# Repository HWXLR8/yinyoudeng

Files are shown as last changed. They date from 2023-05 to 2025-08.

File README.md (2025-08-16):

# 音游灯

<p float="left">
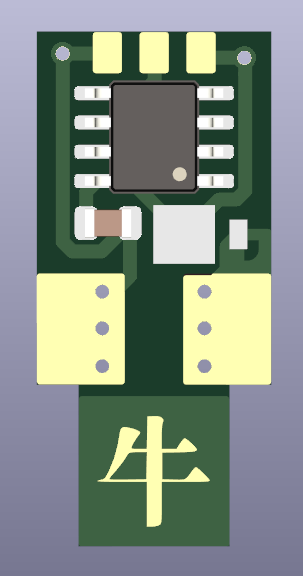
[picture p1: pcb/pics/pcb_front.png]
  
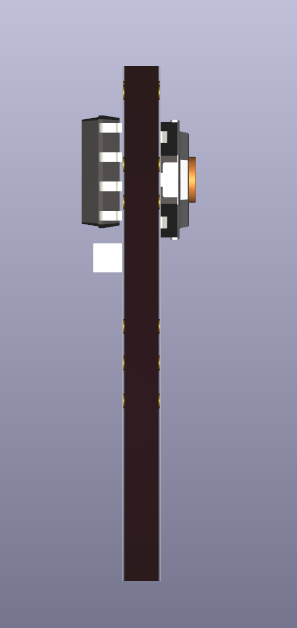
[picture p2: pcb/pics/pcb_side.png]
  
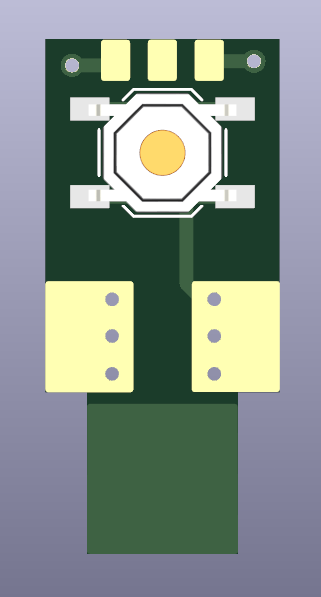
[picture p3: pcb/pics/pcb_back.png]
  
</p>
This is an RGB LED for use with Sanwa rhythm game buttons (also compaitible with many chinese clone buttons). Intended to be soldered to those cheap WS2812 circular PCBs readily available on Aliexpress which include on-board current limiting resistors and decoupling caps:

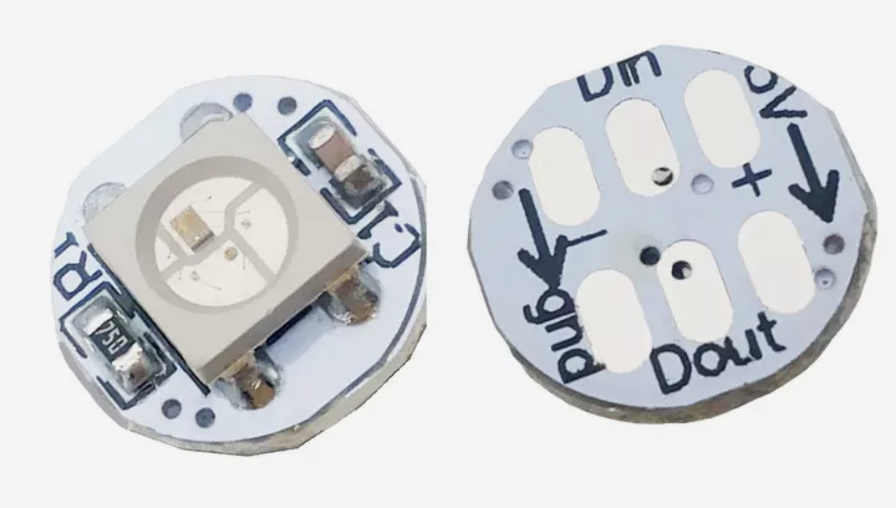
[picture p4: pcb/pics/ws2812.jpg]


BOM:
```
1 ATTINY13A-SSU
1 100nF SMD cap 0805
1 schottky diode (MFG# UPS115UE3)
1 4x4x1.5mm tactile SMD tactile push button
1 WS2812 LED on PCB with res+cap
```
PCBs should be manufactured at 2.0mm thickness instead of standard 1.6mm. Soldering the WS2812 module on to the PCB can be a bit tricky, so I designed a jig which simplifies the alignment of the parts. The model is available in `jig/jig.stl`.

Special thanks to Tim (cpldcpu) for the <a href="https://github.com/cpldcpu/light_ws2812">implementation of
the WS2812 protocol</a>.

享受音游 享受生活

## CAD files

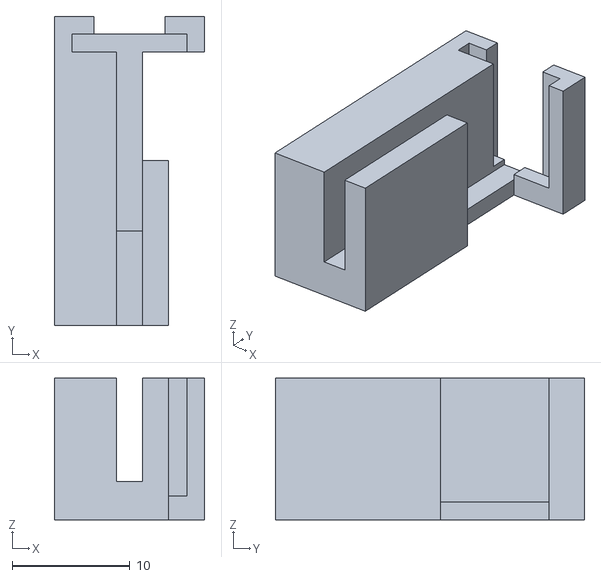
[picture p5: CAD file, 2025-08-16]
jig/jig.stl
12.8 x 26.2 x 12.0

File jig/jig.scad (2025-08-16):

$fn = 50;

include <BOSL2/std.scad>

mid_w = 2.2;
mid_l = 9;
mid_h = 1.5;

ledge_l = 8;
ledge_h = mid_h + 1.75;
ledge_side_h = mid_h + 10.5;

bridge_l = 6.2;

side_w = mid_w;
lside_l = mid_l + bridge_l;
rside_l = 6;
side_h = mid_h + 3;

light_t = 1.5;
light_w = 10 - 0.25;
light_h = ledge_side_h;
light_elevation = 0.5;
light_grip = 0.35;

flush_side = (light_w - mid_w + (light_t * 2)) / 2;

// mid section
cuboid([mid_w, mid_l, mid_h], anchor=BOT) {
  // left side
  attach (LEFT, RIGHT, align=BOT+FRONT) {
    cuboid([flush_side, lside_l, ledge_side_h]) {
      // raised left side
      attach (FRONT, BACK, align=BOT+RIGHT) {
        cuboid([flush_side, ledge_l, ledge_side_h]);
      }
    }
  }

  // raised mid-section
  attach (FRONT, BACK, align=BOT) {
    cuboid([side_w, ledge_l, ledge_h]) {
      // raised right side
      attach (RIGHT, LEFT, align=BOT+FRONT) {
        cuboid([side_w, ledge_l, ledge_side_h]) {
          attach (BACK, FRONT) {
            cuboid([side_w, rside_l, ledge_side_h]);
          }
        }
      }
    }
  }

  attach (BACK, FRONT) {
    // bridge between base and light
    cuboid([mid_w, bridge_l, mid_h]) {
      attach (BACK, FRONT, align=BOT) {
        // light base
        cuboid([light_w, light_t, mid_h]) {
          attach (TOP, BOT, align=RIGHT) {
            // right elevation
            cuboid([(light_w - mid_w) / 2, light_t, light_elevation]);
          }
          attach (TOP, BOT, align=LEFT) {
            // left elevation
            cuboid([(light_w - mid_w) / 2, light_t, light_elevation]);
          }
          attach (BACK, FRONT, align=BOT+RIGHT) {
            // light back-right bar
            cuboid([light_t + light_grip, light_t, light_h]);
          }
          attach (BACK, FRONT, align=BOT+LEFT) {
            // light back-left bar
            cuboid([light_t + light_grip, light_t, light_h]);
          }
          attach (LEFT, RIGHT, align=BOT+FRONT) {
            // left guard
            cuboid([light_t, light_t*2, light_h]);
          }
          attach (RIGHT, LEFT, align=BOT+FRONT) {
            // right guard
            cuboid([light_t, light_t*2, light_h]);
          }
        }
      }
    }
  }
}

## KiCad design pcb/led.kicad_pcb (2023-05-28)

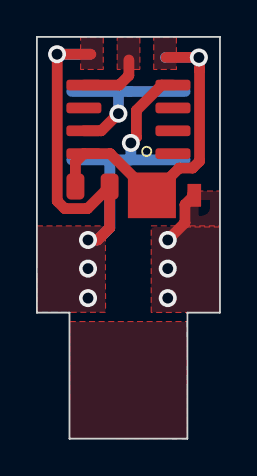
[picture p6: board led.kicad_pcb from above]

Board: 2 copper layers, 10.2 x 22.3 mm, 4 parts (1 on the bottom side), 3 nets.

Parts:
C1: 100nF; C_0805_2012Metric
D2: D_Schottky; D_Powermite_AK
SW1: SW_Push; SW_SPST_TL3342
U1: ATtiny13A-SS; SOIC-8_3.9x4.9mm_P1.27mm

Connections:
GND: C1.2, SW1.2, U1.4 (GND)
unnamed: C1.1, D2.1 (K), U1.8 (VCC)
unnamed: SW1.1, U1.7 (PB2)

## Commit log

2023-08-07 add PCB thickness disclaimer to README
2025-08-16 add jig for soldering alignement
    [jig.scad, jig.stl]
